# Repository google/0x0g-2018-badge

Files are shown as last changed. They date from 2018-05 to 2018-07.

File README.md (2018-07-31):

## About ##

This is the electronic badge distributed at 0x0G, Google's annual event at
DEF CON/Black Hat.  This badge features a PIC microcontroller driving a ring of
LEDs with communication over infrared.

Included are circuit design files and firmware source.  Both are licensed under
the Apache 2 license.

This is not an officially supported Google product.  This is a one-time release,
do not expect updates even if it turns out we have bugs.

## Authors ##

If you have any questions about the badge, feel free to contact one of the
creators:

- matir@google.com
- jsonp@google.com
- claymore@google.com

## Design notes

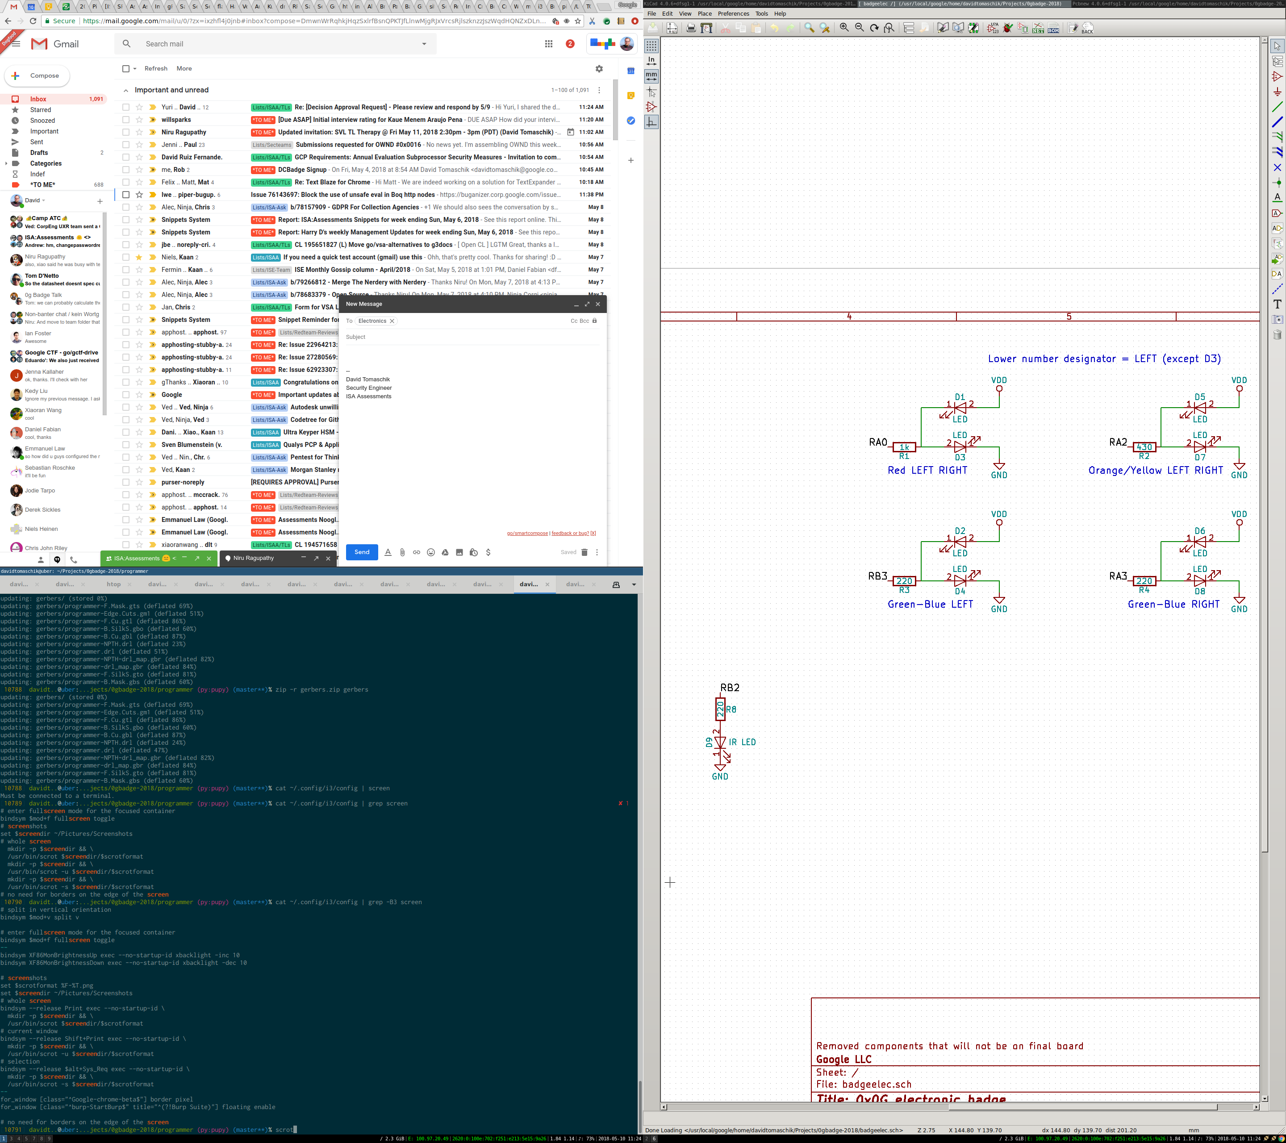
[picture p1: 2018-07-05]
programmer/2018-05-10-112427_2880x2560_scrot.png

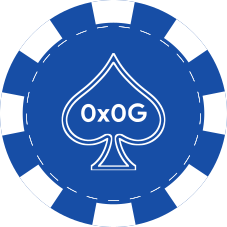
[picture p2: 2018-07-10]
graphics/pokerchip.svg.png

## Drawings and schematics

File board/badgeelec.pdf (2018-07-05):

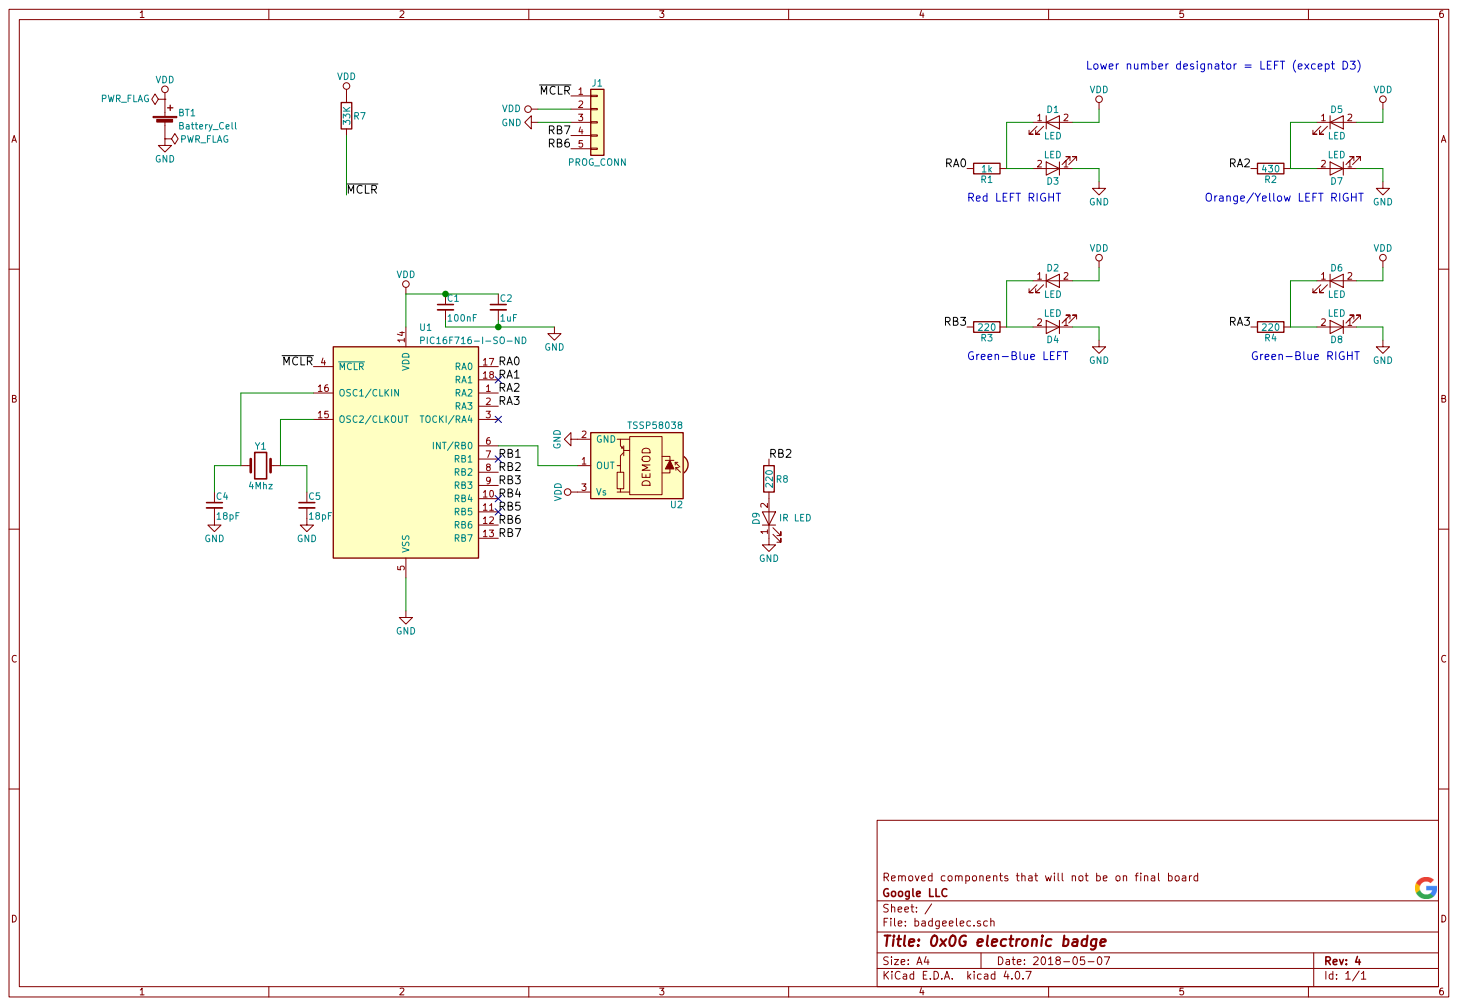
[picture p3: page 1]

Lower number designator = LEFT (except D3) RB3

VDD Orange/Yellow LEFT RIGHT

VDD Green-Blue LEFT

Removed components that will not be on final board
File: badgeelec.sch Sheet: / Google LLC

Id: 1/1 Title: 0x0G electronic badge

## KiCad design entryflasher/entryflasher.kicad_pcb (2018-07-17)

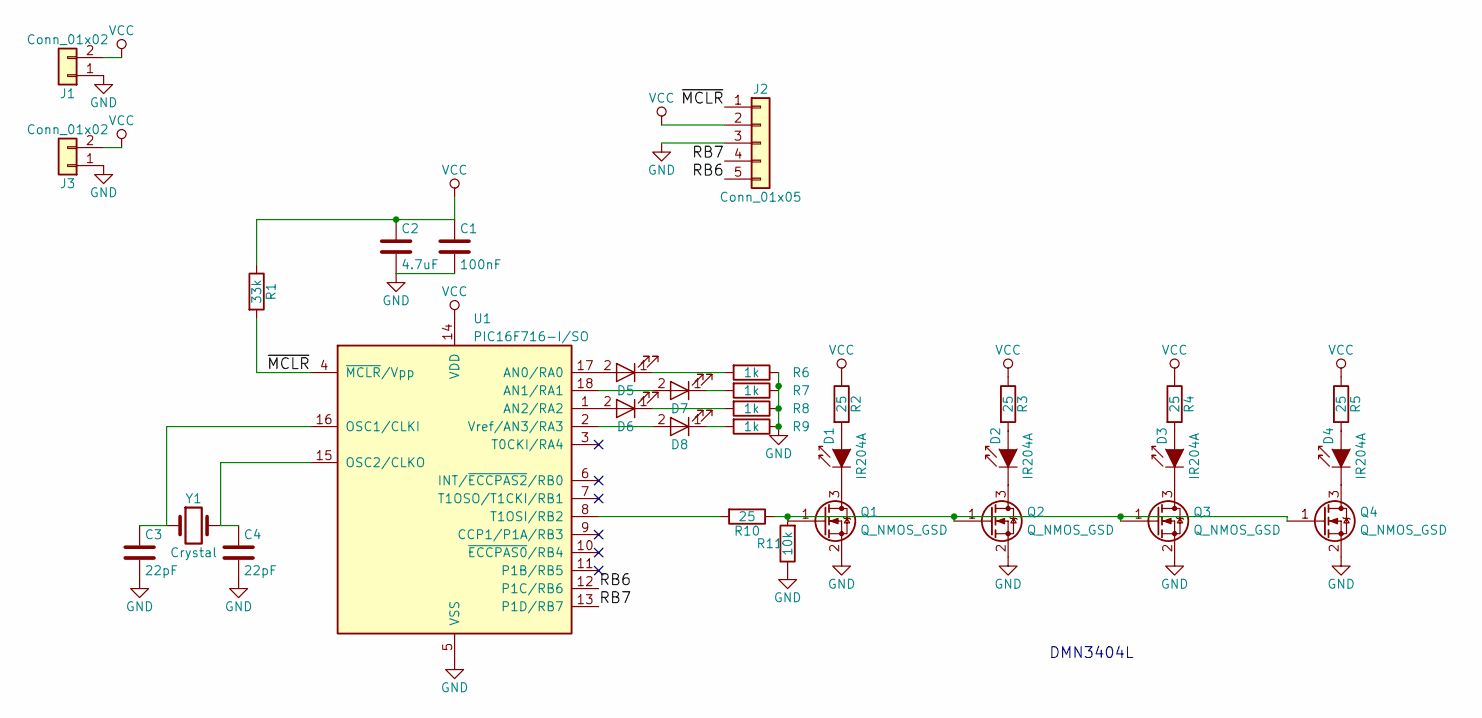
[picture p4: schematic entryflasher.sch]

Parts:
C1: 100nF; C_0805_HandSoldering
C2: 4.7uF; C_0805_HandSoldering
C3, C4: 22pF; C_0805_HandSoldering
D1, D2, D3, D4: IR204A; LED-3MM
D5, D6, D7, D8: LED; LED_0805_HandSoldering
J1, J3: Conn_01x02; Pin_Header_Straight_1x02
J2: Conn_01x05; Pin_Header_Straight_1x05
Q1, Q2, Q3, Q4: Q_NMOS_GSD; SOT-23_Handsoldering
R1: 33k; R_0805_HandSoldering
R2, R3, R4, R5, R10: 25; R_0805_HandSoldering
R6, R7, R8, R9: 1k; R_0805_HandSoldering
R11: 10k; R_0805_HandSoldering
U1: PIC16F716-I/SO; SOIC-18W_7.5x11.6mm_Pitch1.27mm
Y1: Crystal; ABLS-4MHZ-B2-T

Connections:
/RB6: J2.5, U1.12 (P1C/RB6)
/RB7: J2.4, U1.13 (P1D/RB7)
/~MCLR: J2.1, R1.2, U1.4 (~MCLR~/Vpp)
GND: C1.2, C2.2, C3.2, C4.2, J1.1, J2.3, J3.1, Q1.2 (S), Q2.2 (S), Q3.2 (S), Q4.2 (S), R6.1, R7.1, R8.1, R9.1, R11.1, U1.5 (VSS)
unnamed: C3.1, U1.16 (OSC1/CLKI), Y1.1
unnamed: C4.1, U1.15 (OSC2/CLKO), Y1.2
unnamed: D1.1 (K), Q1.3 (D)
unnamed: D1.2 (A), R2.2
unnamed: D2.1 (K), Q2.3 (D)
unnamed: D2.2 (A), R3.2
unnamed: D3.1 (K), Q3.3 (D)
unnamed: D3.2 (A), R4.2
unnamed: D4.1 (K), Q4.3 (D)
unnamed: D4.2 (A), R5.2
unnamed: D5.1 (K), R6.2
unnamed: D5.2 (A), U1.17 (AN0/RA0)
unnamed: D6.1 (K), R8.2
unnamed: D6.2 (A), U1.1 (AN2/RA2)
unnamed: D7.1 (K), R7.2
unnamed: D7.2 (A), U1.18 (AN1/RA1)
unnamed: D8.1 (K), R9.2
unnamed: D8.2 (A), U1.2 (Vref/AN3/RA3)
unnamed: Q1.1 (G), Q2.1 (G), Q3.1 (G), Q4.1 (G), R10.1, R11.2
unnamed: R10.2, U1.8 (T1OSI/RB2)
VCC: C1.1, C2.1, J1.2, J2.2, J3.2, R1.1, R2.1, R3.1, R4.1, R5.1, U1.14 (VDD)

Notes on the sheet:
DMN3404L

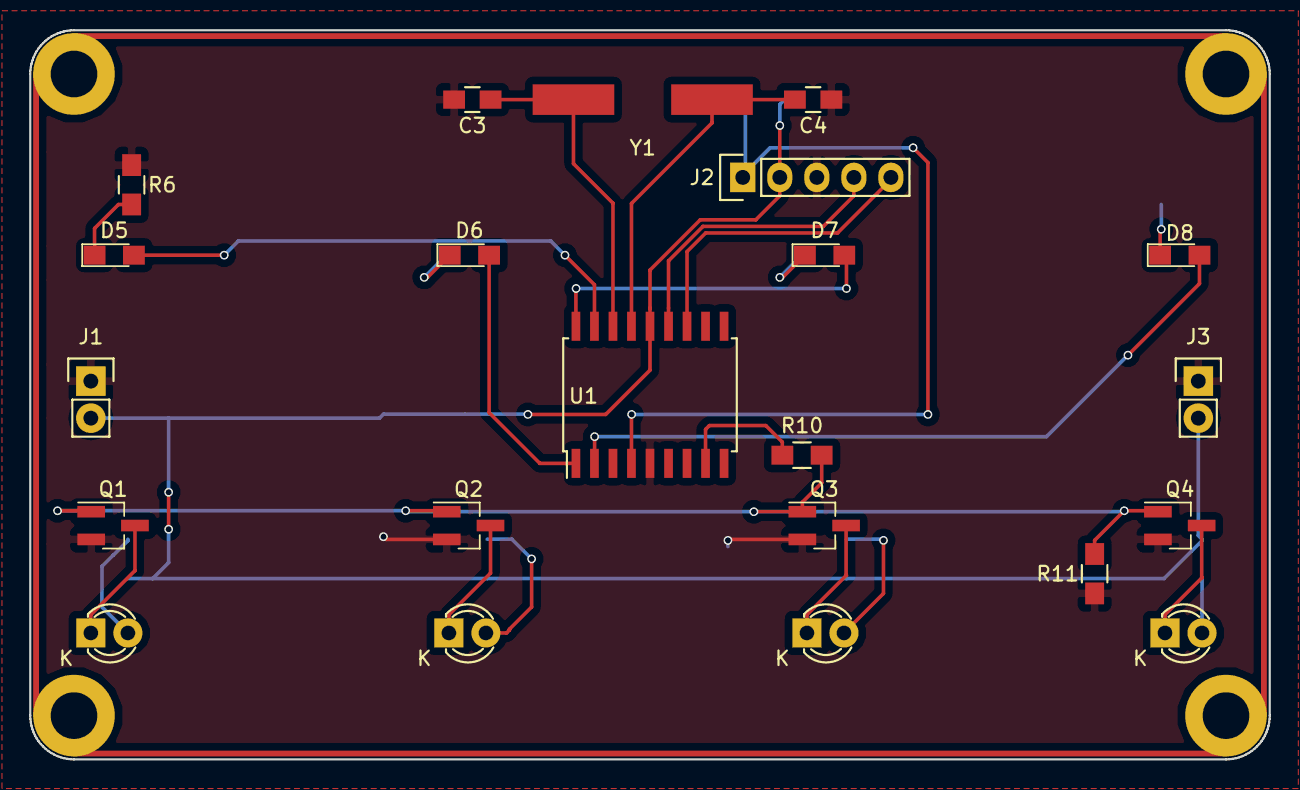
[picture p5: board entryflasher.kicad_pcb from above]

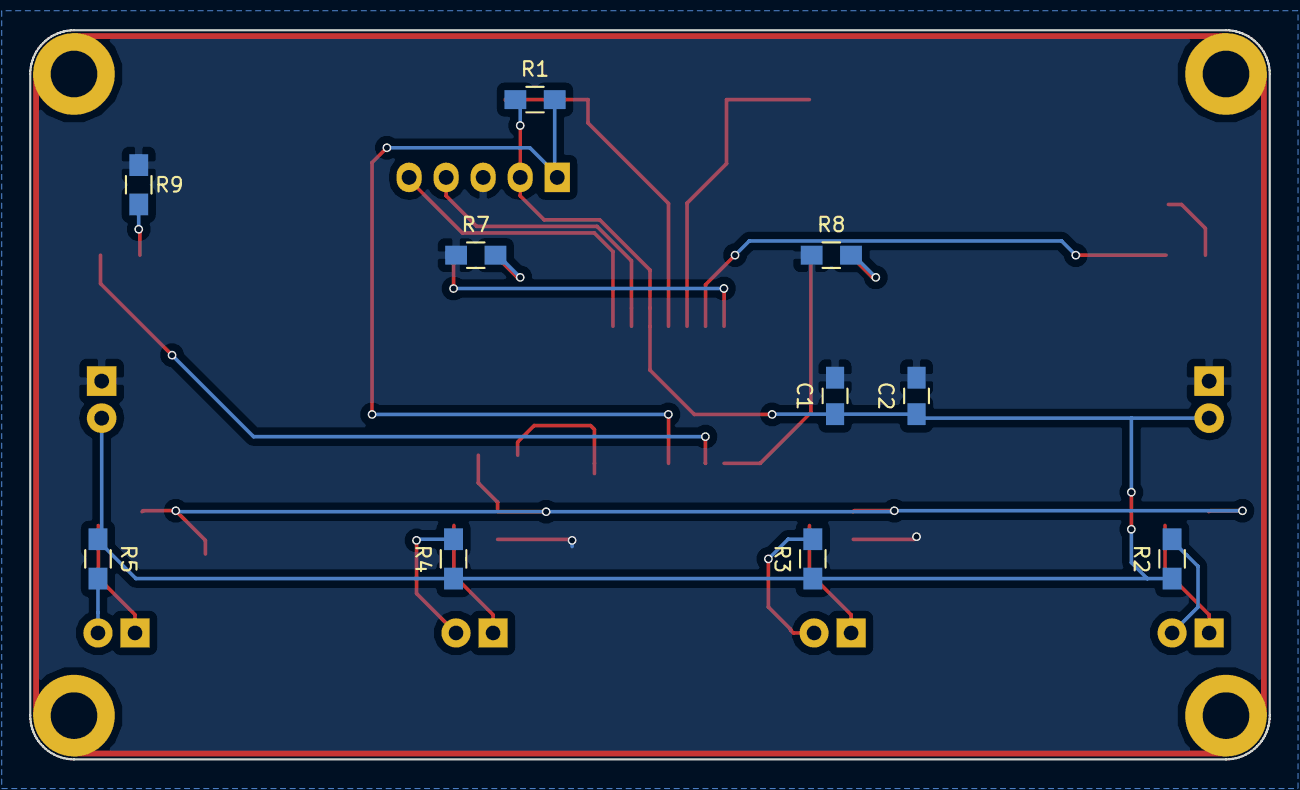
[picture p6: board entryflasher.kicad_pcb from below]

Board: 2 copper layers, 85.0 x 50.0 mm, 32 parts (10 on the bottom side), 25 nets.

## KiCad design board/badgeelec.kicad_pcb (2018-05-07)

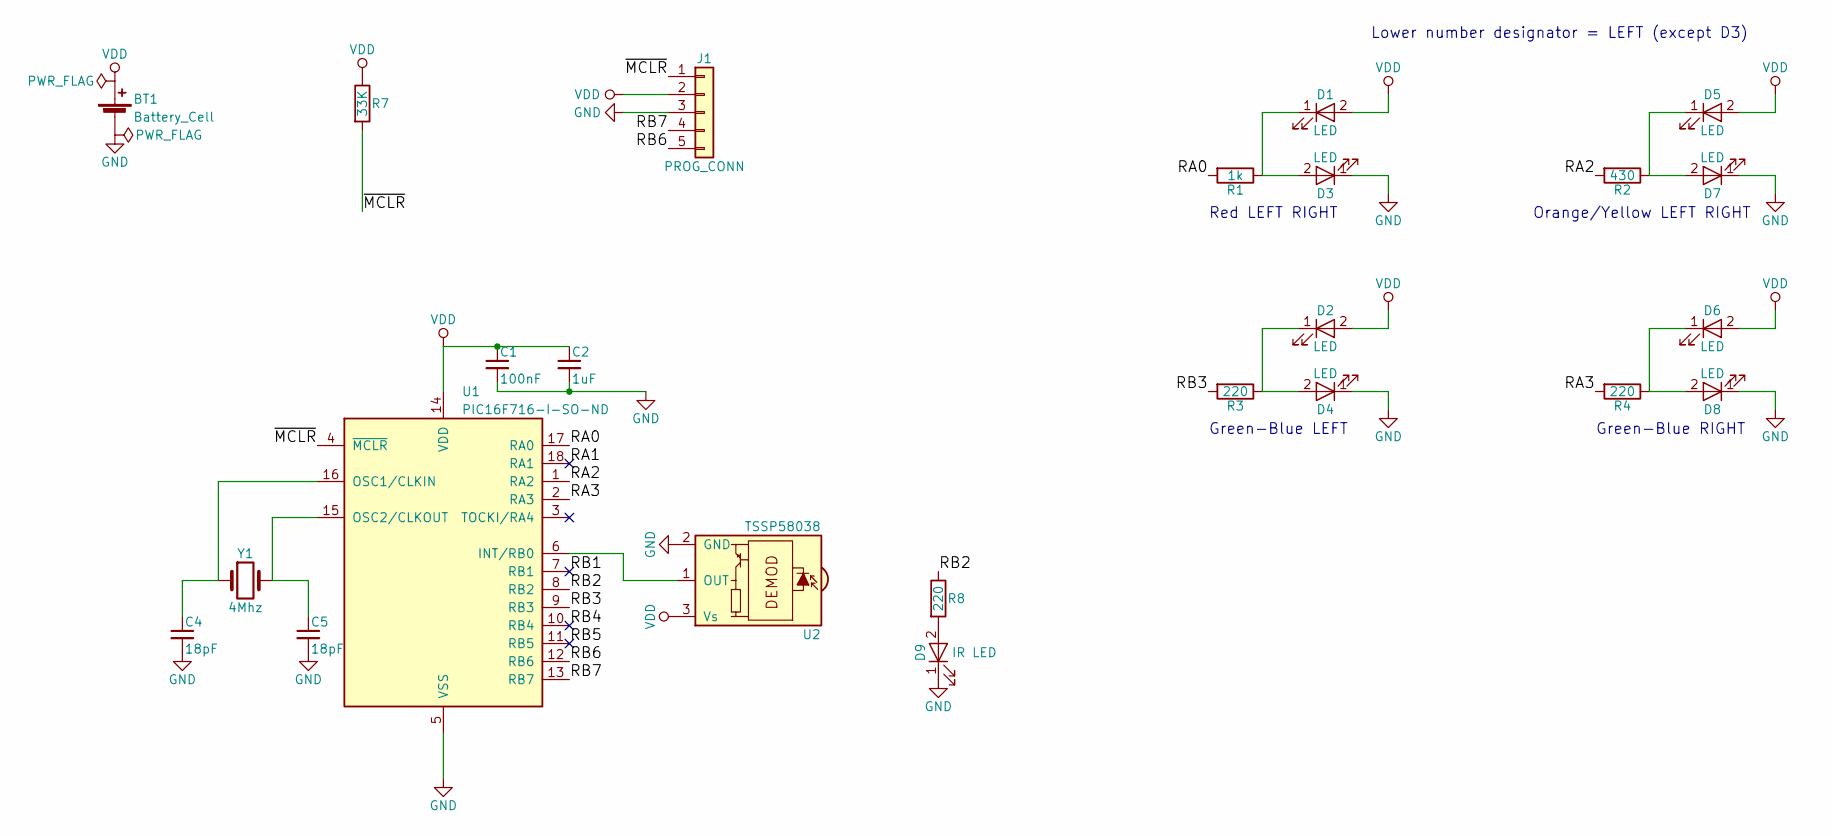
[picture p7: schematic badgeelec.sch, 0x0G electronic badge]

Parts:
BT1: Battery_Cell; BC-2003-TR
C1: 100nF; C_0805
C2: 1uF; C_0805
C4, C5: 18pF; C_0805
D1, D2, D3, D4, D5, D6, D7, D8: LED; LED_0805
D9: IR LED; LED_D3.0mm
J1: PROG_CONN; SMD_PROG_5
R1: 1k; R_0805_HandSoldering
R2: 430; R_0805_HandSoldering
R3, R4, R8: 220; R_0805_HandSoldering
R7: 33K; R_0805_HandSoldering
U1: PIC16F716-I-SO-ND; SOIC-18W_7.5x11.6mm_Pitch1.27mm
U2: TSSP58038; tssp58038_flat
Y1: 4Mhz; ABLS-4MHZ-B2-T

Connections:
/RA0: R1.2, U1.17 (RA0)
/RA1: U1.18 (RA1)
/RA2: R2.2, U1.1 (RA2)
/RA3: R4.2, U1.2 (RA3)
/RB1: U1.7 (RB1)
/RB2: R8.1, U1.8 (RB2)
/RB3: R3.2, U1.9 (RB3)
/RB4: U1.10 (RB4)
/RB5: U1.11 (RB5)
/RB6: J1.5, U1.12 (RB6)
/RB7: J1.4, U1.13 (RB7)
/~MCLR: J1.1, R7.2, U1.4 (~MCLR~)
GND: BT1.2 (-), C1.2, C2.2, C4.2, C5.2, D3.1 (K), D4.1 (K), D7.1 (K), D8.1 (K), D9.1 (K), J1.3, U1.5 (VSS), U2.2 (GND)
unnamed: C4.1, U1.16 (OSC1/CLKIN), Y1.1
unnamed: C5.1, U1.15 (OSC2/CLKOUT), Y1.2
unnamed: D1.1 (K), D3.2 (A), R1.1
unnamed: D2.1 (K), D4.2 (A), R3.1
unnamed: D5.1 (K), D7.2 (A), R2.1
unnamed: D6.1 (K), D8.2 (A), R4.1
unnamed: D9.2 (A), R8.2
unnamed: U1.6 (INT/RB0), U2.1 (OUT)
VDD: BT1.1 (+), C1.1, C2.1, D1.2 (A), D2.2 (A), D5.2 (A), D6.2 (A), J1.2, R7.1, U1.14 (VDD), U2.3 (Vs)

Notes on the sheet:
Red LEFT RIGHT
Green-Blue LEFT
Orange/Yellow LEFT RIGHT
Green-Blue RIGHT
Lower number designator = LEFT (except D3)

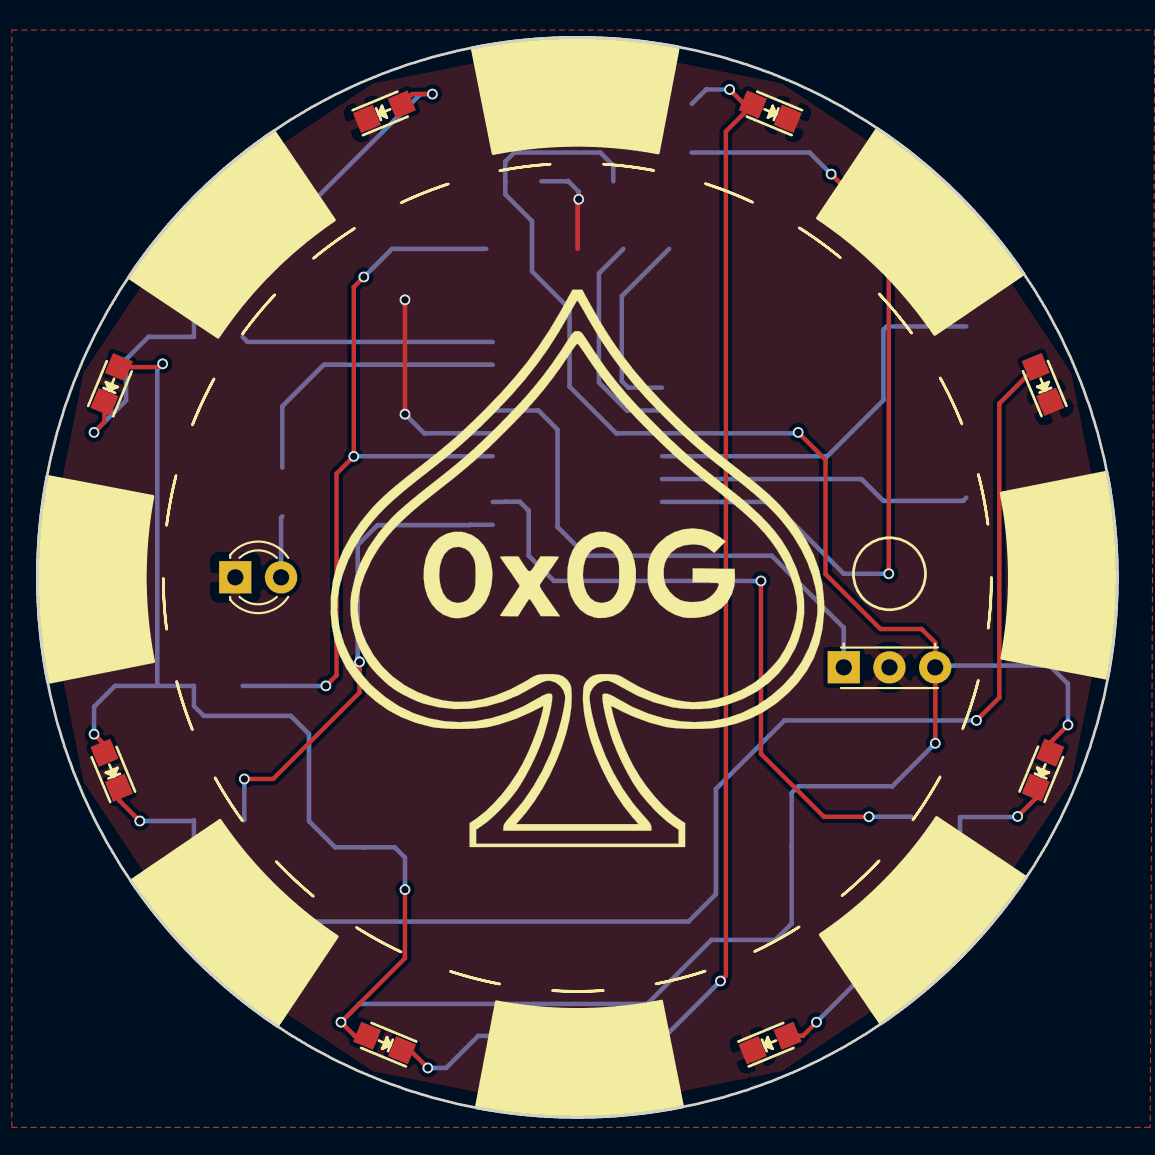
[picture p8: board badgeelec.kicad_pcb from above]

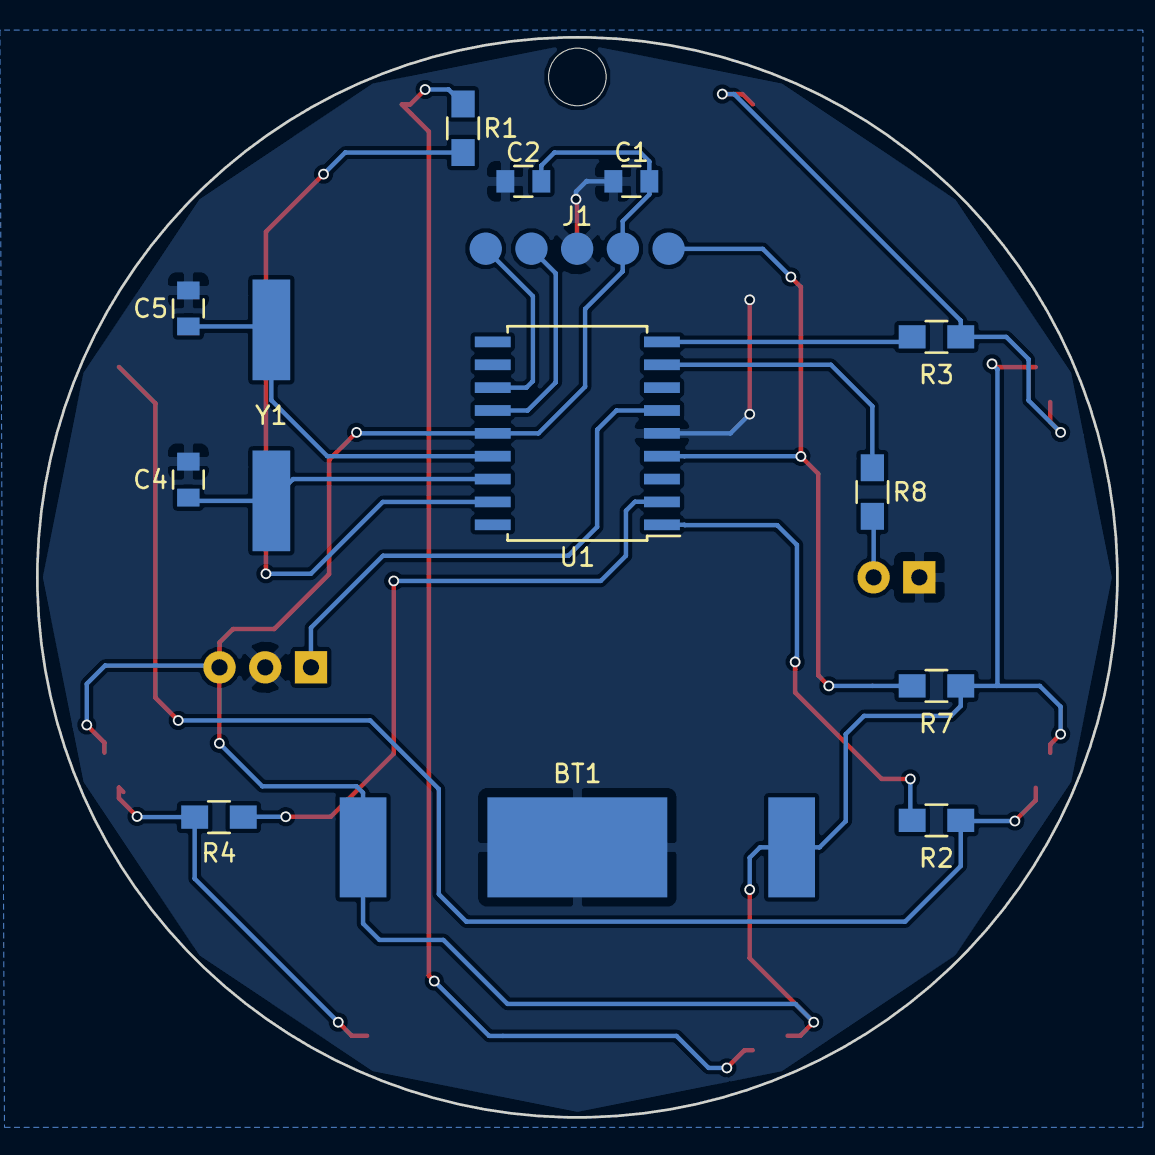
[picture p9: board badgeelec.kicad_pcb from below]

Board: 2 copper layers, 60.0 x 60.0 mm, 24 parts (14 on the bottom side), 18 nets.

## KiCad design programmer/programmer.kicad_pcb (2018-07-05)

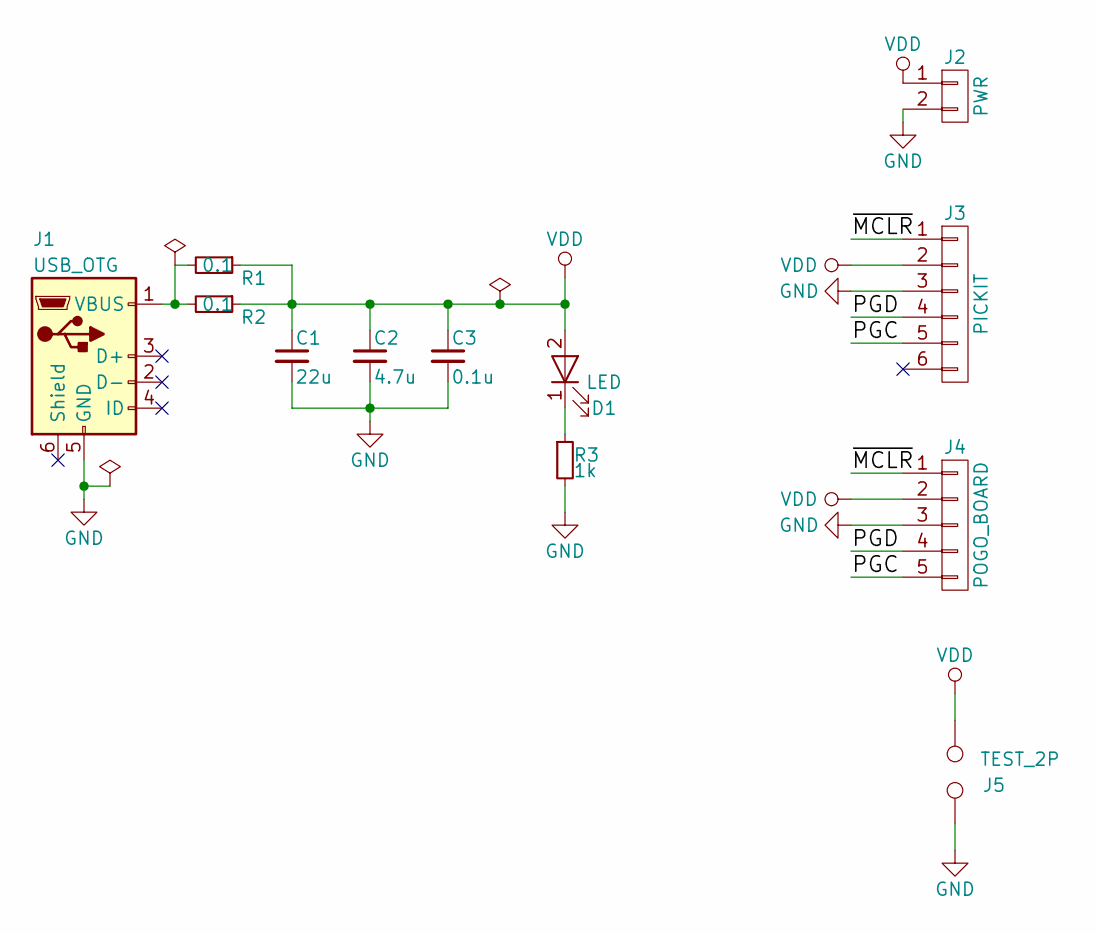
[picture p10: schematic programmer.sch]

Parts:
C1: 22u; C_1206_HandSoldering
C2: 4.7u; C_1206_HandSoldering
C3: 0.1u; C_1206_HandSoldering
D1: LED; LED_0805_HandSoldering
J1: USB_OTG; USB_Micro-B_Amphenol_10103594-0001LF_Horizontal
J2: PWR; Pin_Header_Angled_1x02_Pitch2.54mm
J3: PICKIT; Pin_Header_Angled_1x06_Pitch2.54mm
J4: POGO_BOARD; Pin_Header_Straight_1x05_Pitch2.54mm
J5: TEST_2P; Test_Point_2Pads
R1, R2: 0.1; R_1206_HandSoldering
R3: 1k; R_0805_HandSoldering

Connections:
/PGC: J3.5, J4.5
/PGD: J3.4, J4.4
/~MCLR: J3.1, J4.1
GND: C1.2, C2.2, C3.2, J1.5 (GND), J2.2, J3.3, J4.3, J5.2, R3.2
unnamed: D1.1 (K), R3.1
unnamed: J1.1 (VBUS), R1.2, R2.2
VDD: C1.1, C2.1, C3.1, D1.2 (A), J2.1, J3.2, J4.2, J5.1, R1.1, R2.1

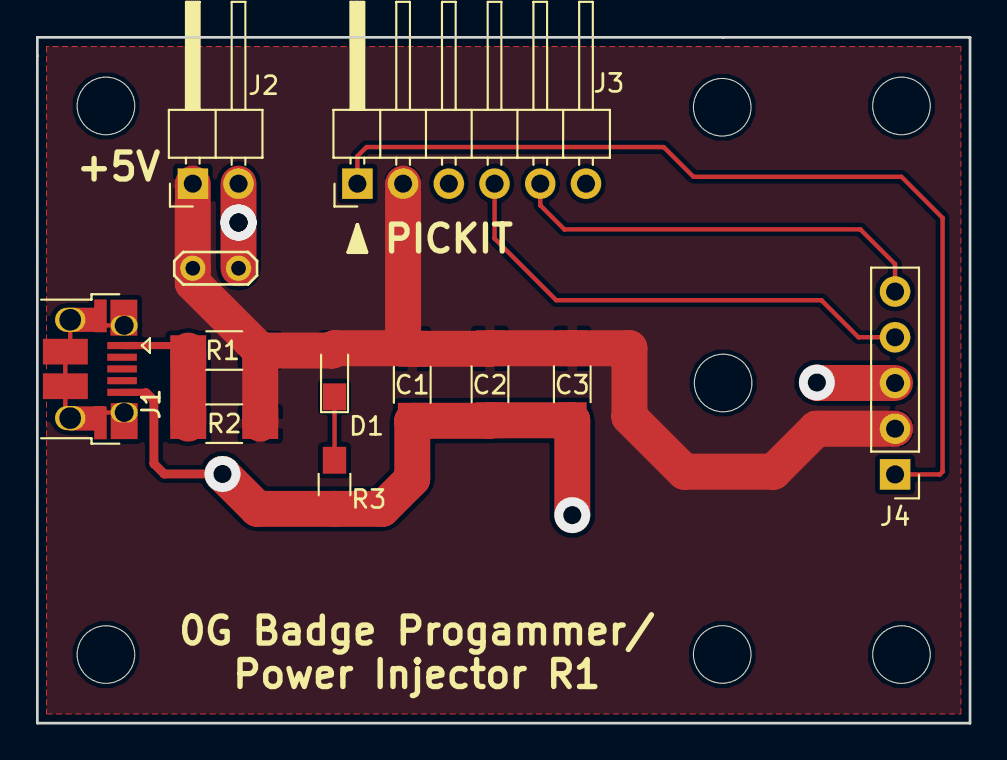
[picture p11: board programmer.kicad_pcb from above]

Board: 2 copper layers, 51.8 x 38.1 mm, 12 parts (0 on the bottom side), 7 nets.

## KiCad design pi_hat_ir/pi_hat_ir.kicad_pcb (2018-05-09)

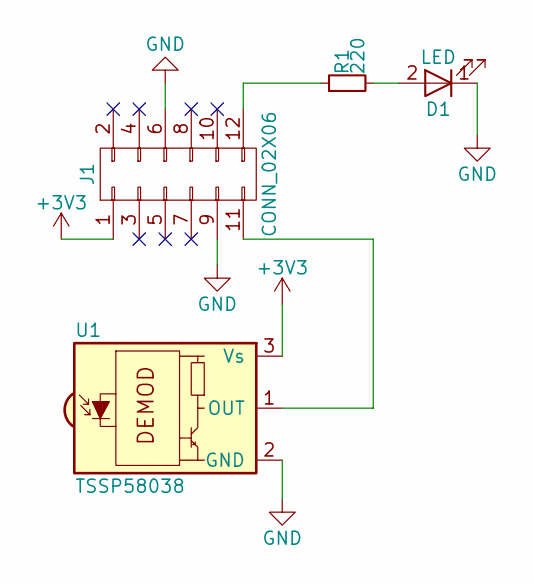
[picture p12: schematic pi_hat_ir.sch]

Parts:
D1: LED; LED_D3.0mm
J1: CONN_02X06; Pin_Header_Straight_2x06_Pitch2.54mm
R1: 220; R_0805_HandSoldering
U1: TSSP58038; IRReceiver_Vishay_MINICAST-3pin

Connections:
+3V3: J1.1, U1.3 (Vs)
GND: D1.1 (K), J1.6, J1.9, U1.2 (GND)
unnamed: D1.2 (A), R1.2
unnamed: J1.11, U1.1 (OUT)
unnamed: J1.12, R1.1

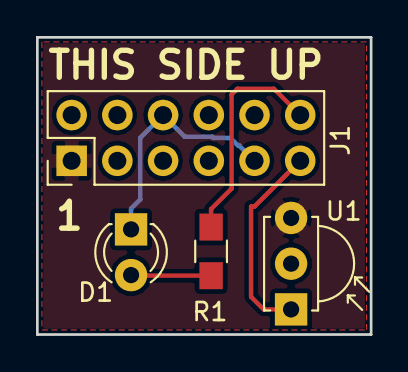
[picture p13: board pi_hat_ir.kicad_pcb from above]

Board: 2 copper layers, 18.5 x 16.5 mm, 4 parts (0 on the bottom side), 5 nets.

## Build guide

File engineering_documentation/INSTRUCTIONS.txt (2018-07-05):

 - The 'down' side of the PCB can be determined by the text on the front side. Additionally, the test points used for programming (designator J1) are torwards the top of the board on the REVERSE side.
 - All LEDs are polarized such that their negative side / cathode faces the bottom of the PCB (cathode closer to the bottom than the anode). The silkscreen should also indicate this.
 - The PIC chip is polarized such that the dot must face the 'down' side of the PCB.
 - The IR reciever (through-hole component) MUST be oriented correctly. Once soldered in, it should be bent at right-angles so its body is flush with the PCB, and the curved window faces away from the PCB..
 - Do not put any solder paste on the center (larger) pad of the battery holder (BT1). The battery makes direct contact with this pad.

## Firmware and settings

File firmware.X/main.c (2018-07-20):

/*
 * Copyright 2018 Google LLC
 *
 * Licensed under the Apache License, Version 2.0 (the "License");
 * you may not use this file except in compliance with the License.
 * You may obtain a copy of the License at
 *
 *      http://www.apache.org/licenses/LICENSE-2.0
 *
 * Unless required by applicable law or agreed to in writing, software
 * distributed under the License is distributed on an "AS IS" BASIS,
 * WITHOUT WARRANTIES OR CONDITIONS OF ANY KIND, either express or implied.
 * See the License for the specific language governing permissions and
 * limitations under the License.
 */

/*
 * File:   main.c
 * Author: David
 *
 * Created on May 15, 2018, 3:16 AM
 */

// CONFIG
#pragma config FOSC = XT        // Oscillator Selection bits (XT oscillator)
#pragma config WDTE = OFF       // Watchdog Timer Enable bit (WDT enabled)
#pragma config PWRTE = OFF      // Power-up Timer Enable bit (PWRT disabled)
#pragma config BOREN = OFF      // Brown-out Reset Enable bit (BOR disabled)
#pragma config BODENV = 40      // Brown-out Reset Voltage bit (VBOR set to 4.0V)
#pragma config CP = OFF         // Code Protect (Program memory code protection is disabled)

#include <xc.h>

#include "ir_decoder.h"
#include "ir_transmitter.h"
#include "leds.h"

volatile uint8_t move_leds = 1;
// Transmitting or receiving?
volatile uint8_t ir_transmitting = 0;
// Are we locked into a mode
volatile uint8_t mode_locked = 0;

static void service_led_modes(uint16_t ird);

static void interrupt ISR(void) {
    if (INTCONbits.T0IF) {
        if (move_leds)
            timer0_interrupt();
        else
            INTCONbits.T0IF = 0;
    }
    if (PIR1bits.TMR1IF) {
        if (!ir_transmitting) {
            timer1_interrupt_decoder();
        } else {
            PIR1bits.TMR1IF = 0;
        }
    }
}

void main(void) {
    timer0_setup();
    setup_ir_decoder();
    setup_ir_transmitter();
    
    while (1) {
        service_leds();
        if (ir_data_valid > 0) {
            uint16_t ird = ir_data & 0xFFFF;
            if (ird != IR_BITS_ON)
                sync_led_pos();
            if (!mode_locked) {
                service_led_modes(ird);
            }
            ir_data_valid = 0;
        }
    }
}

static void service_led_modes(uint16_t ird) {
    if (ird == IR_BITS_LIGHTER_BLUE) {
        seen_blue_team();
    }
    else if (ird == IR_BITS_LIGHTER_RED) {
        seen_red_team();
    }
    else if (ird == IR_BITS_LIGHTER_YELLOW) {
        seen_yellow_team();
    }
    else if (ird == IR_BITS_LIGHTER_GREEN) {
        seen_green_team();
    }
    else if (ird == IR_BITS_BLUE) {
        mode_locked = 1;
        set_led_mode(LMODE_BLUE_TEAM);
    }
    else if (ird == IR_BITS_RED) {
        mode_locked = 1;
        set_led_mode(LMODE_RED_TEAM);
    }
    else if (ird == IR_BITS_GREEN) {
        mode_locked = 1;
        set_led_mode(LMODE_GREEN_TEAM);
    }
    else if (ird == IR_BITS_WHITE) {
        mode_locked = 1;
        set_led_mode(LMODE_YELLOW_TEAM);
    }
    else if (ird == IR_BITS_BRIGHTNESS_UP) {
        mode_locked = 1;
        set_led_mode(LMODE_CHASE_FAST);
    }
    else if (ird == IR_BITS_BRIGHTNESS_DOWN) {
        set_led_mode(LMODE_CHASE_1);
    }
    else if (ird == IR_BITS_FLASH) {
        set_led_mode(LMODE_CHASE_2);
    }
    else if (ird == IR_BITS_OFF) {
        set_led_mode(LMODE_OFF);
    }
    else if (ird == IR_BITS_ON) {
        set_led_mode(LMODE_PARTICIPANT_CHASE);
    }
    else if (ird == IR_BITS_LIGHTER_PINK) {
        clear_seen_teams();
    }
    else if (ird == IR_BITS_STROBE) {
        set_led_mode(LMODE_BLUE_RED);
    }
}

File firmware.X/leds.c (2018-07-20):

/*
 * Copyright 2018 Google LLC
 *
 * Licensed under the Apache License, Version 2.0 (the "License");
 * you may not use this file except in compliance with the License.
 * You may obtain a copy of the License at
 *
 *      http://www.apache.org/licenses/LICENSE-2.0
 *
 * Unless required by applicable law or agreed to in writing, software
 * distributed under the License is distributed on an "AS IS" BASIS,
 * WITHOUT WARRANTIES OR CONDITIONS OF ANY KIND, either express or implied.
 * See the License for the specific language governing permissions and
 * limitations under the License.
 */

#include <stdint.h>

#include <xc.h>

#include "leds.h"
#include "ir_transmitter.h"

volatile uint16_t led_pos = 0;
volatile uint8_t seen_teams = 0;
volatile uint8_t led_mode = LMODE_CHASE_2; // default mode

#define LED_RED_LEFT()          leda_on(0, 0)
#define LED_RED_RIGHT()         leda_on(0, 1)
#define LED_YELLOW_LEFT()       leda_on(2, 0)
#define LED_YELLOW_RIGHT()      leda_on(2, 1)
#define LED_GREEN_LEFT()        ledb_on(3, 0)
#define LED_GREEN_RIGHT()       leda_on(3, 0)
#define LED_BLUE_LEFT()         ledb_on(3, 1)
#define LED_BLUE_RIGHT()        leda_on(3, 1)

static inline void all_off();
static inline void leda_on(uint8_t pos, uint8_t dir);
static inline void ledb_on(uint8_t pos, uint8_t dir);

void sync_led_pos() {
    led_pos = 248;
}

void set_led_mode(uint8_t mode){
    led_mode = mode;
}

/*
 * Turn on exactly one LED
 */
void exactly_on(uint8_t which) {
    all_off();
    switch (which) {
        case 0:
            LED_RED_LEFT();
            break;
        case 1:
            LED_YELLOW_LEFT();
            break;
        case 2:
            LED_GREEN_LEFT();
            break;
        case 3:
            LED_BLUE_LEFT();
            break;
        case 4:
            LED_RED_RIGHT();
            break;
        case 5:
            LED_YELLOW_RIGHT();
            break;
        case 6:
            LED_GREEN_RIGHT();
            break;
        case 7:
            LED_BLUE_RIGHT();
            break;
    }
}

/*
 * Turn all LEDs off
 */
static inline void all_off() {
    TRISA |= 1 | (1 << 2) | (1 << 3);
    TRISB |= (1 << 3);
}

/*
 * Turn a LED on on PORTA
 */
static inline void leda_on(uint8_t pos, uint8_t dir) {
    if (dir)
        PORTA |= (1u<<pos);
    else
        PORTA &= ~(1u<<pos);
    TRISA &= ~(1u<<pos);
}

/*
 * Turn a LED on on PORTB
 */
static inline void ledb_on(uint8_t pos, uint8_t dir) {
    if (dir)
        PORTB |= (1u<<pos);
    else
        PORTB &= ~(1u<<pos);
    TRISB &= ~(1u<<pos);
}

void timer0_interrupt(void) {
    led_pos++;
    led_pos &= 0b11111111111;
    INTCONbits.T0IF = 0;  // Clear flag
}

void static inline bits3_chase(uint8_t pos) {
    switch (pos) {
     default:
     case 0:
         LED_RED_LEFT();
         break;
     case 1:
         LED_YELLOW_LEFT();
         break;
     case 2:
         LED_GREEN_LEFT();
         break;
     case 3:
         LED_BLUE_LEFT();
         break;
     case 4:
         LED_RED_RIGHT();
         break;
     case 5:
         LED_YELLOW_RIGHT();
         break;
     case 6:
         LED_GREEN_RIGHT();
         break;
     case 7:
         LED_BLUE_RIGHT();
         break;
    }
}

void static inline bits2_double_chase(uint8_t pos, uint8_t side) {
    switch (pos) {
     default:
     case 0:
         if (side)
            LED_RED_LEFT();
         else
            LED_RED_RIGHT();
         break;
     case 1:
         if (side)
            LED_YELLOW_LEFT();
         else
            LED_YELLOW_RIGHT();
         break;
     case 2:
         if (side)
            LED_GREEN_LEFT();
         else
            LED_GREEN_RIGHT();
         break;
     case 3:
         if (side)
            LED_BLUE_LEFT();
         else
            LED_BLUE_RIGHT();
         break;
    }
}

void static inline blue_team_led(uint16_t pos) {
    if (pos < 1024) {
        all_off();
        if (pos == 0) {
            transmit_word((uint8_t)((IR_BITS_LIGHTER_BLUE_R >> 8) & 0xFF), (uint8_t)(IR_BITS_LIGHTER_BLUE_R & 0xFF));
        } else {
            if ((pos%2) == 0)
                LED_BLUE_RIGHT();
            else
                LED_BLUE_LEFT();
        }
    } else {
        uint8_t v = (((pos - 1024) / 256) + 3) % 4;
        all_off();
        bits2_double_chase(v, pos%2);
    }
}

void static inline red_team_led(uint16_t pos) {
    if (pos < 1024) {
        all_off();
        if (pos == 0) {
            transmit_word((uint8_t)((IR_BITS_LIGHTER_RED_R >> 8) & 0xFF), (uint8_t)(IR_BITS_LIGHTER_RED_R & 0xFF));
        } else {
            if ((pos%2) == 0)
                LED_RED_RIGHT();
            else
                LED_RED_LEFT();
        }
    } else {
        uint8_t v = (((pos - 1024) / 256) + 0) % 4;
        all_off();
        bits2_double_chase(v, pos%2);
    }
}

void static inline yellow_team_led(uint16_t pos) {
    if (pos < 1024) {
        all_off();
        if (pos == 0) {
            transmit_word((uint8_t)((IR_BITS_LIGHTER_YELLOW_R >> 8) & 0xFF), (uint8_t)(IR_BITS_LIGHTER_YELLOW_R & 0xFF));
        } else {
            if ((pos%2) == 0)
                LED_YELLOW_RIGHT();
            else
                LED_YELLOW_LEFT();
        }
    } else {
        uint8_t v = (((pos - 1024) / 256) + 1) % 4;
        all_off();
        bits2_double_chase(v, pos%2);
    }
}

void static inline green_team_led(uint16_t pos) {
    if (pos < 1024) {
        all_off();
        if (pos == 0) {
            transmit_word((uint8_t)((IR_BITS_LIGHTER_GREEN_R >> 8) & 0xFF), (uint8_t)(IR_BITS_LIGHTER_GREEN_R & 0xFF));
        } else {
            if ((pos%2) == 0)
                LED_GREEN_RIGHT();
            else
                LED_GREEN_LEFT();
        }
    } else {
        uint8_t v = (((pos - 1024) / 256) + 2) % 4;
        all_off();
        bits2_double_chase(v, pos%2);
    }
}

void service_participant_chase(uint16_t pos) {
    if (pos < 1024) {
        uint8_t v = ((pos & 0b111111111) / 64);
        all_off();
        bits3_chase(v);
    } else {
        uint8_t v = (pos % 32) / 16;
        all_off();
        if (pos < 1536) {
            if (pos < 1280 && ((seen_teams & RED_TEAM_BIT) != 0))
                bits2_double_chase(0, v);
            else if ((seen_teams & GREEN_TEAM_BIT) != 0)
                bits2_double_chase(2, v);
        } else {
            if (pos < 1792 && ((seen_teams & YELLOW_TEAM_BIT) != 0))
                bits2_double_chase(1, v);
            else if ((seen_teams & BLUE_TEAM_BIT) != 0)
                bits2_double_chase(3, v);
        }
    }
}

void bluered_flash(uint16_t pos) {
    uint8_t v = (pos % 32) / 16;
    uint8_t side = (pos / 256) % 2;
    all_off();
    if (side == 0)
        bits2_double_chase(0, v);
    else
        bits2_double_chase(3, v);
}
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

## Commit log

2018-03-09 prototype r1
    [badgeelec.kicad_pcb, badgeelec.sch]
2018-03-09 add gerbers for prototype r1
    [badgeelec-B.Cu.gbl, badgeelec-B.Mask.gbs, badgeelec-B.SilkS.gbo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]
2018-03-12 Added more BOM detail
    [badgeelec.sch]
2018-03-28 additional details
    [badgeelec.kicad_pcb]
2018-04-09 Halfway through v2
    [badgeelec.kicad_pcb, badgeelec.sch]
2018-04-10 Implemented prototypev2
    [badgeelec.kicad_pcb, badgeelec.sch]
2018-04-23 Schematic for final layout prototype 1
    [badgeelec.sch]
2018-04-23 Start working on layout for final prototype 1
    [badgeelec.kicad_pcb]
2018-04-23 Start working on generator to produce graphics footprint
2018-04-25 Created/changed IR receiver to horizontal footprint, implemented basic generator for poker-chip style layout
    [badgeelec.kicad_pcb, badgeelec.sch]
2018-04-25 Done layout for proto final v1
    [badgeelec.kicad_pcb]
2018-04-25 Routed prototype final v1
    [badgeelec.kicad_pcb, badgeelec.sch]
2018-04-26 Create gerbers for r2
    [badgeelec-B.Cu.gbl, badgeelec-B.Mask.gbs, badgeelec-B.SilkS.gbo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]
2018-04-26 Forgot prototype silkS module
2018-04-26 check in gerber zip
    [badgeelec.sch]
2018-05-03 Cut revision 3
    [badgeelec-B.Cu.gbl, badgeelec-B.Mask.gbs, badgeelec-B.SilkS.gbo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]
2018-05-03 Cut r4
    [badgeelec-B.Cu.gbl, badgeelec-B.Mask.gbs, badgeelec-B.SilkS.gbo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]
2018-05-07 First pass verifying everything
    [badgeelec.kicad_pcb, badgeelec.sch]
2018-05-09 Add programmer and PI IR Hat.
    [pi_hat_ir-B.Cu.gbl, pi_hat_ir-B.Mask.gbs, pi_hat_ir-B.SilkS.gbo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]
2018-05-09 Fix missing trace.
    [programmer.kicad_pcb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]
2018-05-16 Start work on firmware.
    [firmware_dev.X.production.obj]
2018-05-16 Add LED blinking based on jsonp@s code.
    [firmware.X.production.obj]
2018-05-16 Add solder paste instructions
2018-05-16 Uploadable firmware.
    [firmware.X.production.obj]
2018-05-19 IR decoder work.
    [firmware.X.production.obj]
2018-05-19 Fix ir_decoder.c
    [firmware.X.production.obj]
2018-05-19 Fully working decoder.
    [firmware.X.production.obj]
2018-06-11 Refactor LED control, fix LED clear
    [leds.c, main.c]
2018-06-11 Implement flashing modes for LED
2018-07-05 Preparing for release v1.
    [badgeelec.kicad_pcb, badgeelec.sch]
2018-07-05 Update programmer
    [programmer-B.Cu.gbl, programmer-B.Mask.gbs, programmer-B.SilkS.gbo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]
2018-07-05 Clean up release warnings.
    [firmware.X.production.obj, firmware_dev.X.production.obj]
2018-07-11 Add entryflasher PCB to repo
    [entryflasher-B.Cu.gbr, entryflasher-B.Mask.gbr, entryflasher-B.SilkS.gbr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]
2018-07-17 Fix NEC transmission with EOM marker.
    [ir_transmitter.c]
2018-07-18 Implement new LED modes
